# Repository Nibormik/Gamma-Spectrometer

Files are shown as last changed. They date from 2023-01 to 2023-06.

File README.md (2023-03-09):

# Gamma-Spectrometer
This is a Compact Gammaspectrometer Based On the Scematics and component choise of the [Open-Gamma-Detector](https://github.com/Open-Gamma-Project/Open-Gamma-Detector).
Its only Designed for testing purposes and should never be used in a production enviorment.  
<br>
This version of the Gamma spectrometer was designed with a few strict restrictions in mind.

#### Restrictions
<br>
The main rrestrictions:  <br>

- Power
    - <= 50ma
    - 5v
    - low noise
- physical limitations
    - pcb
        - width 50mm
        - height 30 mm
    - rocket interior diameter 98mm
        - max center height from pcb 38 mm
        - max edge height from pcb 28 mm 
- comunication
    - analog rocket input
        - update frequencey 2000hz - 4000hz
        - 8 bit resolution
    - digital input
        - 8bit digital paralell
        - estimated update frequency 20hz

## Similarities between projects

Since this is based upon the schematic of the Open Gamma Detector there are not allot of diffrences.  
Main diffrences are a diffrent cpu and the data output (wich is stricly analog)
Due to the enviorment, to-way comunictation is not possible so the bord does not support it.

The scintilator end general operational methon of the systen is equal to that of the Opgen Gamma Detector

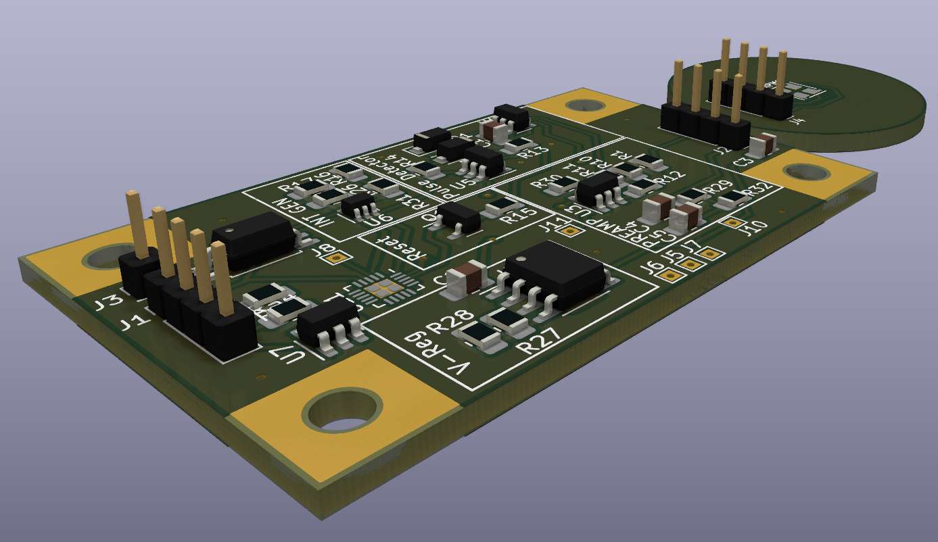
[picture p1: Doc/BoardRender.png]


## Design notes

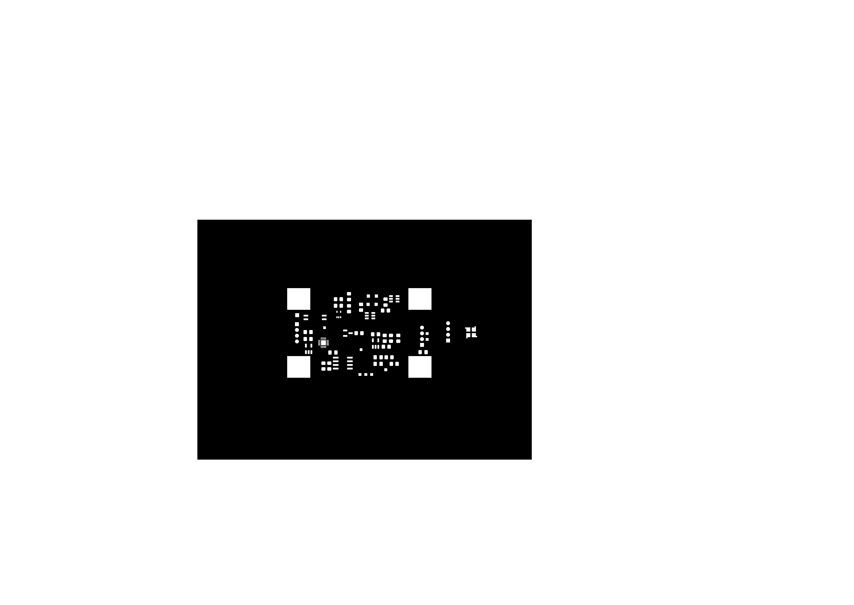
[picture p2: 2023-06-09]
Hardware/Pcb file/Gamma_spectrometer-F_Mask.png

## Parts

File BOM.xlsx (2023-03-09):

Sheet: Manglende Komponenter!
iD | AMOUT | LABEL | COMPONENT NAVN | KOMENTAR | FOOTPRINT | DATASHEET | KJØPS LINK
1 | 1 | Q1 | 2N7002 | Kan Erstates Med lignende Komponenter | Package_TO_SOT_SMD:SOT-23 | https://www.onsemi.com/pub/Collateral/NDS7002A-D.PDF | https://no.farnell.com/nexperia/2n7002-215/mosfet-n-ch-60v-0-3a-sot23/dp/1510761
2 | 1 | U2 | LM317L_SO8 | Regulator_Linear:LM317L_SO8 | Package_SO:SOIC-8_3.9x4.9mm_P1.27mm | http://www.ti.com/lit/ds/snvs775k/snvs775k.pdf | https://no.farnell.com/on-semiconductor/lm317lbdr2g/linear-volt-reg-adj-37v-0-1a-soic/dp/2534167?st=lm317l
3 | 2 | U3, U7 | OPA356AIDBVR | Amplifier_Operational:OPA356xxDBVR | Package_TO_SOT_SMD:SOT-23-5 | http://www.ti.com/lit/ds/symlink/opa356.pdf | https://www.digikey.no/en/products/detail/OPA356AIDBVT/296-12619-1-ND/446313
4 | 2 | U4, U5 | OPA357AIDBVR | Amplifier_Operational:OPA357xxDBVR | Package_TO_SOT_SMD:SOT-23-6 | http://www.ti.com/lit/ds/symlink/opa355.pdf | https://www.digikey.no/en/products/detail/texas-instruments/OPA357AIDBVR/1572552
5 | 1 | U6 | TLV3201AIDBVR |  | Package_TO_SOT_SMD:SOT-353_SC-70-5 |  | https://no.farnell.com/texas-instruments/tlv3201aidbvr/comparator-single-40ns-sot-23/dp/3005605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
6 | 1 | U8 | FODM217A | Kan Erstates Med lignende Komponenter | Package_SO:SOP-4_4.4x2.6mm_P1.27mm | https://www.onsemi.com/pub/Collateral/FODM214-D.PDF
7 | 1 | U11 | ATtiny1616-M | MCU_Microchip_ATtiny:ATtiny1616-M | Package_DFN_QFN:VQFN-20-1EP_3x3mm_P0.4mm_EP1.7x1.7mm | http://ww1.microchip.com/downloads/en/DeviceDoc/ATtiny3216_ATtiny1616-data-sheet-40001997B.pdf | https://no.farnell.com/microchip/attiny1616-mfr/mcu-8bit-avr-20mhz-vqfn-24/dp/2783011?st=attiny1616-m

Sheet: Gamma_spectrometer (4)
Column1 | Column2 | Column3 | Column4 | Column5 | Column6 | Column7 | Column8 | Column9 | Column10 | Column11
Source: | C:\Users\Nibne\Documents\Gamma Spectrometer\Hardware\Gamma_spectrometer.kicad_sch
Date: | 2/6/2023 2:52:58 PM
Tool: | Eeschema (6.0.8)
Generator: | C:\Program Files\KiCad\6.0\bin\scripting\plugins/bom_csv_grouped_by_value.py
Component Count: | 47
Individual Components:
Item | Qty | Reference(s) | Value | LibPart | Footprint | Datasheet | MANUFACTURER | MAXIMUM_PACKAGE_HEIGHT | PARTREV | STANDARD
 |  | C1 | C | Device:C | Capacitor_SMD:C_0805_2012Metric_Pad1.18x1.45mm_HandSolder | ~
 |  | C2 | C | Device:C | Capacitor_SMD:C_0805_2012Metric_Pad1.18x1.45mm_HandSolder | ~
 |  | C3 | C | Device:C | Capacitor_SMD:C_0805_2012Metric_Pad1.18x1.45mm_HandSolder | ~
 |  | C4 | 10n | Device:C | Capacitor_SMD:C_0805_2012Metric_Pad1.18x1.45mm_HandSolder | ~
 |  | C5 | 10n | Device:C | Capacitor_SMD:C_0805_2012Metric_Pad1.18x1.45mm_HandSolder | ~
 |  | D1 | PMEG6010CEH | Diode:PMEG6010CEH | Diode_SMD:D_SOD-123F | https://assets.nexperia.com/documents/data-sheet/PMEG6010CEH_PMEG6010CEJ.pdf
 |  | D2 | PMEG6010CEH | Diode:PMEG6010CEH | Diode_SMD:D_SOD-123F | https://assets.nexperia.com/documents/data-sheet/PMEG6010CEH_PMEG6010CEJ.pdf
 |  | J1 | Conn_01x04 | Connector_Generic:Conn_01x04 | Connector_PinHeader_2.00mm:PinHeader_1x04_P2.00mm_Vertical | ~
 |  | J2 | Conn_01x04 | Connector_Generic:Conn_01x04 | Connector_PinHeader_2.00mm:PinHeader_1x04_P2.00mm_Vertical | ~
 |  | J3 | Conn_01x01 | Connector_Generic:Conn_01x01 | Connector_PinHeader_2.00mm:PinHeader_1x01_P2.00mm_Vertical | ~
 |  | J4 | Conn_01x04 | Connector_Generic:Conn_01x04 | Connector_PinHeader_2.00mm:PinHeader_1x04_P2.00mm_Vertical | ~
 |  | J5 | Test Pad | Connector:Conn_01x01_Female | TestPoint:TestPoint_THTPad_1.0x1.0mm_Drill0.5mm | ~
 |  | J6 | Test Pad | Connector:Conn_01x01_Female | TestPoint:TestPoint_THTPad_1.0x1.0mm_Drill0.5mm | ~
 |  | J7 | Test Pad | Connector:Conn_01x01_Female | TestPoint:TestPoint_THTPad_1.0x1.0mm_Drill0.5mm | ~
 |  | J8 | Test Pad | Connector:Conn_01x01_Female | TestPoint:TestPoint_THTPad_1.0x1.0mm_Drill0.5mm | ~
 |  | J9 | Test Pad | Connector:Conn_01x01_Female | TestPoint:TestPoint_THTPad_1.0x1.0mm_Drill0.5mm | ~
 |  | J10 | Test Pad | Connector:Conn_01x01_Female | TestPoint:TestPoint_THTPad_1.0x1.0mm_Drill0.5mm | ~
 |  | J11 | Test Pad | Connector:Conn_01x01_Female | TestPoint:TestPoint_THTPad_1.0x1.0mm_Drill0.5mm | ~
 |  | J12 | Test Pad | Connector:Conn_01x01_Female | TestPoint:TestPoint_THTPad_1.0x1.0mm_Drill0.5mm | ~
 |  | Q1 | 2N7002 | Transistor_FET:2N7002 | Package_TO_SOT_SMD:SOT-23 | https://www.onsemi.com/pub/Collateral/NDS7002A-D.PDF
 |  | R1 | 49.9 | Device:R | Resistor_SMD:R_0805_2012Metric_Pad1.20x1.40mm_HandSolder | ~
 |  | R10 | 10 | Device:R | Resistor_SMD:R_0805_2012Metric_Pad1.20x1.40mm_HandSolder | ~
 |  | R11 | 10 | Device:R | Resistor_SMD:R_0805_2012Metric_Pad1.20x1.40mm_HandSolder | ~
 |  | R12 | 49.9 | Device:R | Resistor_SMD:R_0805_2012Metric_Pad1.20x1.40mm_HandSolder | ~
 |  | R13 | 49.9 | Device:R | Resistor_SMD:R_0805_2012Metric_Pad1.20x1.40mm_HandSolder | ~
 |  | R14 | 1000 | Device:R | Resistor_SMD:R_0805_2012Metric_Pad1.20x1.40mm_HandSolder | ~
 |  | R15 | 1000 | Device:R | Resistor_SMD:R_0805_2012Metric_Pad1.20x1.40mm_HandSolder | ~
 |  | R16 | 1000 | Device:R | Resistor_SMD:R_0805_2012Metric_Pad1.20x1.40mm_HandSolder | ~
 |  | R17 | 107K | Device:R | Resistor_SMD:R_0805_2012Metric_Pad1.20x1.40mm_HandSolder | ~
 |  | R26 | 107K | Device:R | Resistor_SMD:R_0805_2012Metric_Pad1.20x1.40mm_HandSolder | ~
 |  | R27 | ? | Device:R | Resistor_SMD:R_0805_2012Metric_Pad1.20x1.40mm_HandSolder | ~
 |  | R28 | ? | Device:R | Resistor_SMD:R_0805_2012Metric_Pad1.20x1.40mm_HandSolder | ~
 |  | R29 | 49.9 | Device:R | Resistor_SMD:R_0805_2012Metric_Pad1.20x1.40mm_HandSolder | ~
 |  | R30 | ? | Device:R | Resistor_SMD:R_0805_2012Metric_Pad1.20x1.40mm_HandSolder | ~
 |  | R31 | ? | Device:R | Resistor_SMD:R_0805_2012Metric_Pad1.20x1.40mm_HandSolder | ~
 |  | R32 | 49.9 | Device:R | Resistor_SMD:R_0805_2012Metric_Pad1.20x1.40mm_HandSolder | ~
 |  | R33 | 1000 | Device:R | Resistor_SMD:R_0805_2012Metric_Pad1.20x1.40mm_HandSolder | ~
 |  | R34 | 1000 | Device:R | Resistor_SMD:R_0805_2012Metric_Pad1.20x1.40mm_HandSolder | ~
 |  | SIPM1 | MICROFC-30035-SMT-TR1 | MICROFC-30035-SMT-TR1:MICROFC-30035-SMT-TR1 | MICROFC-30035-SMT-TR1:XDCR_MICROFC-30035-SMT-TR1 |  | On Semiconductor | 0.70 mm | Issue O | Manufacturer Recommendations
 |  | U2 | LM317L_SO8 | Regulator_Linear:LM317L_SO8 | Package_SO:SOIC-8_3.9x4.9mm_P1.27mm | http://www.ti.com/lit/ds/snvs775k/snvs775k.pdf
 |  | U3 | OPA356xxDBV | Amplifier_Operational:OPA356xxDBV | Package_TO_SOT_SMD:SOT-23-5 | http://www.ti.com/lit/ds/symlink/opa356.pdf
 |  | U4 | OPA357AIDVBR | Amplifier_Operational:OPA355NA | Package_TO_SOT_SMD:SOT-23-6 | http://www.ti.com/lit/ds/symlink/opa355.pdf
 |  | U5 | OPA357AIDVBR | Amplifier_Operational:OPA355NA | Package_TO_SOT_SMD:SOT-23-6 | http://www.ti.com/lit/ds/symlink/opa355.pdf
 |  | U6 | LMV7219M7 | Comparator:LMV7219M7 | Package_TO_SOT_SMD:SOT-353_SC-70-5 | https://www.ti.com/lit/ds/symlink/lmv7219.pdf
 |  | U7 | OPA356xxDBV | Amplifier_Operational:OPA356xxDBV | Package_TO_SOT_SMD:SOT-23-5 | http://www.ti.com/lit/ds/symlink/opa356.pdf
 |  | U8 | FODM217A | Isolator:FODM217A | Package_SO:SOP-4_4.4x2.6mm_P1.27mm | https://www.onsemi.com/pub/Collateral/FODM214-D.PDF
 |  | U11 | ATtiny1616-M | MCU_Microchip_ATtiny:ATtiny1616-M | Package_DFN_QFN:VQFN-20-1EP_3x3mm_P0.4mm_EP1.7x1.7mm | http://ww1.microchip.com/downloads/en/DeviceDoc/ATtiny3216_ATtiny1616-data-sheet-40001997B.pdf
Collated Components:
Item | Qty | Reference(s) | Value | LibPart | Footprint | Datasheet | MANUFACTURER | MAXIMUM_PACKAGE_HEIGHT | PARTREV | STANDARD
1 | 3 | C1, C2, C3 | C |  | Capacitor_SMD:C_0805_2012Metric_Pad1.18x1.45mm_HandSolder | ~
2 | 2 | C4, C5 | 10n |  | Capacitor_SMD:C_0805_2012Metric_Pad1.18x1.45mm_HandSolder | ~
3 | 2 | D1, D2 | PMEG6010CEH | Kan Erstates Med lignende Komponenter | Diode_SMD:D_SOD-123F | https://assets.nexperia.com/documents/data-sheet/PMEG6010CEH_PMEG6010CEJ.pdf
4 | 3 | J1, J2, J4 | Conn_01x04 | 1stk Rakett konnector 2stk pin header | Connector_PinHeader_2.00mm:PinHeader_1x04_P2.00mm_Vertical | ~
5 | 1 | J3 | Conn_01x01 | rakett CLK konnector | Connector_PinHeader_2.00mm:PinHeader_1x01_P2.00mm_Vertical | ~
6 | 8 | J5, J6, J7, J8, J9, J10, J11, J12 | Test Pad |  | TestPoint:TestPoint_THTPad_1.0x1.0mm_Drill0.5mm | ~
7 | 1 | Q1 | 2N7002 | Kan Erstates Med lignende Komponenter | Package_TO_SOT_SMD:SOT-23 | https://www.onsemi.com/pub/Collateral/NDS7002A-D.PDF
8 | 5 | R1, R12, R13, R29, R32 | 49.9 |  | Resistor_SMD:R_0805_2012Metric_Pad1.20x1.40mm_HandSolder | ~
9 | 2 | R10, R11 | 10 |  | Resistor_SMD:R_0805_2012Metric_Pad1.20x1.40mm_HandSolder | ~
10 | 5 | R14, R15, R16, R33, R34 | 1000 |  | Resistor_SMD:R_0805_2012Metric_Pad1.20x1.40mm_HandSolder | ~
11 | 2 | R17, R26 | 107K |  | Resistor_SMD:R_0805_2012Metric_Pad1.20x1.40mm_HandSolder | ~
12 | 4 | R27, R28, R30, R31 | ? | må testes for og finne verdi | Resistor_SMD:R_0805_2012Metric_Pad1.20x1.40mm_HandSolder | ~
13 | 1 | SIPM1 | MICROFC-30035-SMT-TR1 |  | MICROFC-30035-SMT-TR1:XDCR_MICROFC-30035-SMT-TR1 |  | On Semiconductor | 0.70 mm | Issue O | Manufacturer Recommendations
14 | 1 | U2 | LM317L_SO8 | Regulator_Linear:LM317L_SO8 | Package_SO:SOIC-8_3.9x4.9mm_P1.27mm | http://www.ti.com/lit/ds/snvs775k/snvs775k.pdf
15 | 2 | U3, U7 | OPA356AIDBVR | Amplifier_Operational:OPA356xxDBVR | Package_TO_SOT_SMD:SOT-23-5 | http://www.ti.com/lit/ds/symlink/opa356.pdf
16 | 2 | U4, U5 | OPA357AIDBVR | Amplifier_Operational:OPA357xxDBVR | Package_TO_SOT_SMD:SOT-23-6 | http://www.ti.com/lit/ds/symlink/opa355.pdf
17 | 1 | U6 | LMV7219M7 | Comparator:LMV7219M7 | Package_TO_SOT_SMD:SOT-353_SC-70-5 | https://www.ti.com/lit/ds/symlink/lmv7219.pdf
18 | 1 | U8 | FODM217A | Kan Erstates Med lignende Komponenter | Package_SO:SOP-4_4.4x2.6mm_P1.27mm | https://www.onsemi.com/pub/Collateral/FODM214-D.PDF
19 | 1 | U11 | ATtiny1616-M | MCU_Microchip_ATtiny:ATtiny1616-M | Package_DFN_QFN:VQFN-20-1EP_3x3mm_P0.4mm_EP1.7x1.7mm | http://ww1.microchip.com/downloads/en/DeviceDoc/ATtiny3216_ATtiny1616-data-sheet-40001997B.pdf

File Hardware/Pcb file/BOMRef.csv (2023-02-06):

ID | Name | Designator | Footprint | Quantity | Manufacturer Part | Manufacturer | Supplier | Supplier Part | Price
1 | XL-2012UOC | ACT | LED0805-RD_ORANGE | 1 | XL-2012UOC | XINGLIGHT(成兴光) | LCSC | C965813 | 0.008
2 | 4.7uF | C1,C5,C9,C10,C11 | C0805 | 5 | CL21A475KBQNNNE | SAMSUNG | LCSC | C98192 | 0.028
3 | 100nF | C2,C3,C4,C6,C7 | C0805 | 5 | CL21B104KBCNNNC | SAMSUNG | LCSC | C1711 | 0.003
4 | 220pF | C8 | C0805 | 1 | ECHU1H221JX5 | PANASONIC | LCSC | C178426 | 0.279
5 | PMEG6010CEH | D1,D2,D3 | SOD-123FL_L2.7-W1.8-LS3.8-RD | 3 | PMEG6010CEH,115 | NXP | LCSC | C110797 | 0.278
6 | 47uH | L1 | IND-SMD_L5.0-W5.0 | 1 | GCNR5040-470MC | GLE | LCSC | C439375 | 0.057
7 | 2N7002,215 | Q1 | SOT-23_L2.9-W1.3-P1.90-LS2.4-BR | 1 | 2N7002,215 | Nexperia | LCSC | C65189 | 0.042
8 | 107kΩ | R1,R11,R22 | R0805 | 3 | 0805W8F1073T5E | UniOhm | LCSC | C17412 | 0.003
9 | 10kΩ | R2,R9,R10 | RES-ADJ-TH_3P-L10.0-W10.0-P2.50-L | 3 | 3296W-1-103 | Chengdu Guosheng Tech | LCSC | C118954 | 0.151
10 | 1K | R3,R6,R7,R8 | R0805 | 4 | 0805W8F1001T5E | UniOhm | LCSC | C17513 | 0.002
11 | 10Ω | R5,R12,R14 | R0805_NEW | 3 | 0805W8F100JT5E | UniOhm | LCSC | C17415 | 0.002
12 | 10kΩ | R13,R15 | R0805 | 2 | 0805W8F1002T5E | UniOhm | LCSC | C17414 | 0.001
13 | 49.9Ω | R16,R17,R20,R21 | R0805 | 4 | 0805W8F499JT5E | UniOhm | LCSC | C17720 | 0.002
14 | 2kΩ | R19 | RES-ADJ-TH_3296W-L | 1 | 3296W-1-202LF | Bochen | LCSC | C118206 | 0.195
15 | TLV3201AIDBVR | U1 | SOT-23-5_L3.0-W1.7-P0.95-LS2.8-BR | 1 | TLV3201AIDBVR | TI | LCSC | C105188 | 0.554
16 | LM4040AIM3-3.0+T | U2 | SOT-23-3_L2.9-W1.6-P1.90-LS2.8-BR | 1 | LM4040AIM3-3.0+T | MAXIM | LCSC | C143326 | 1.067
17 | PI-PICO-SMD | U3 | RASPBERRY PICO SMD | 1 | Raspberry Pi Pico | Raspberry Pi Ltd |  | Raspberry Pi Pico
18 | MAX5026EUT+T | U5 | SOT-23-6_L2.9-W1.6-P0.95-LS2.8-BL | 1 | MAX5026EUT+T | Maxim Integrated | Mouser | 700-MAX5026EUTT
19 | OPA356AIDBVR | U6 | SOT-23-5_L3.0-W1.7-P0.95-LS2.8-BR | 1 | OPA356AIDBVR | Texas Instruments | LCSC | C183100 | 3.175
20 | OPA357AIDBVR | U7,U8 | SOT-23-6_L2.9-W1.6-P0.95-LS2.8-BR | 2 | OPA357AIDBVR | TI | LCSC | C139385 | 3.515

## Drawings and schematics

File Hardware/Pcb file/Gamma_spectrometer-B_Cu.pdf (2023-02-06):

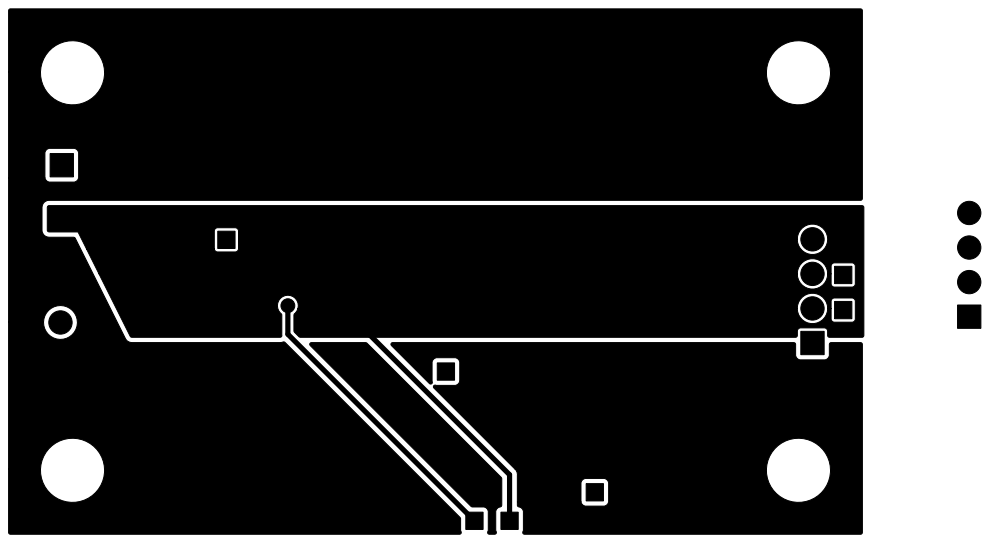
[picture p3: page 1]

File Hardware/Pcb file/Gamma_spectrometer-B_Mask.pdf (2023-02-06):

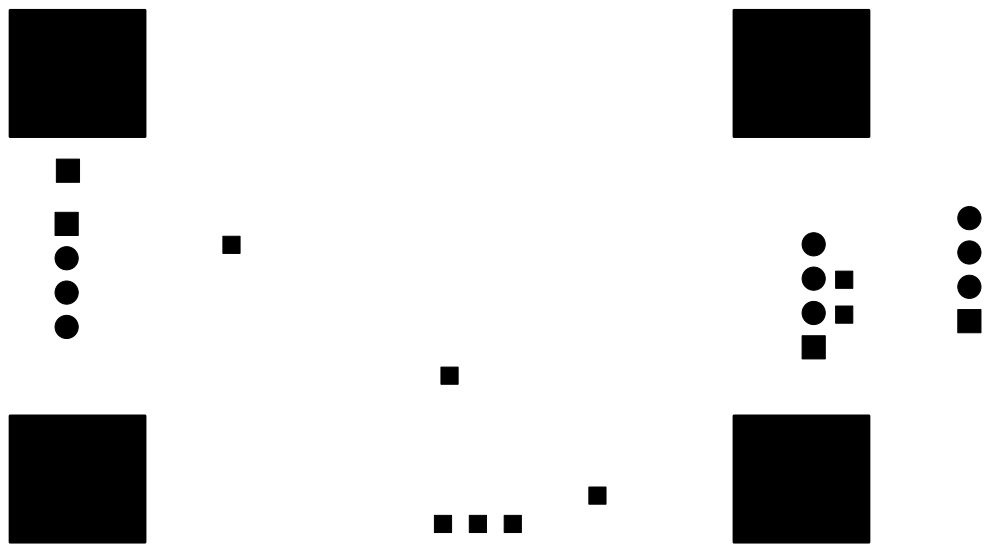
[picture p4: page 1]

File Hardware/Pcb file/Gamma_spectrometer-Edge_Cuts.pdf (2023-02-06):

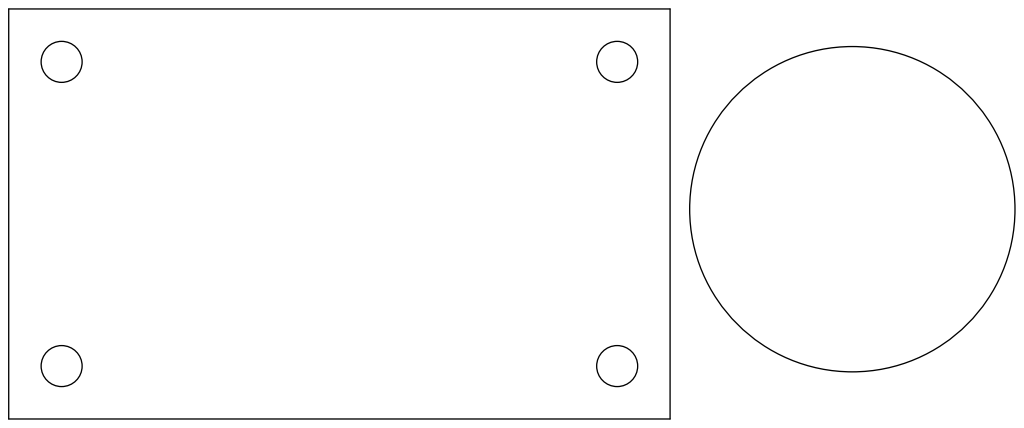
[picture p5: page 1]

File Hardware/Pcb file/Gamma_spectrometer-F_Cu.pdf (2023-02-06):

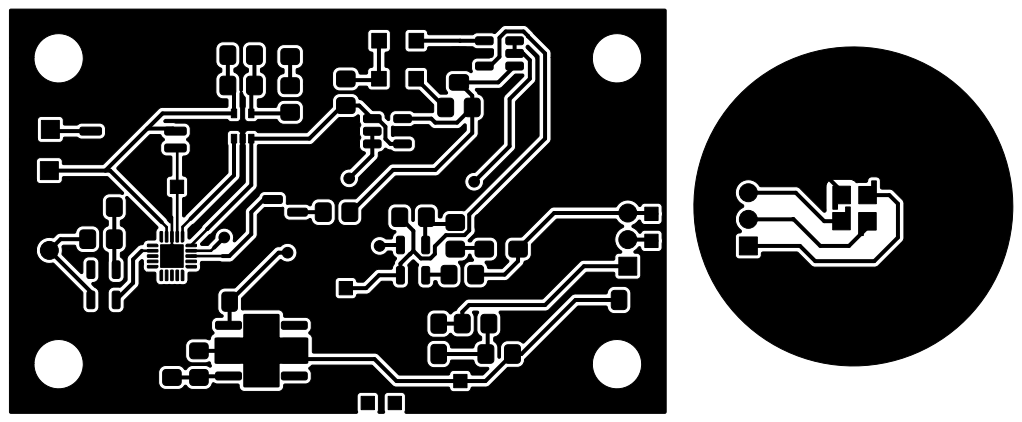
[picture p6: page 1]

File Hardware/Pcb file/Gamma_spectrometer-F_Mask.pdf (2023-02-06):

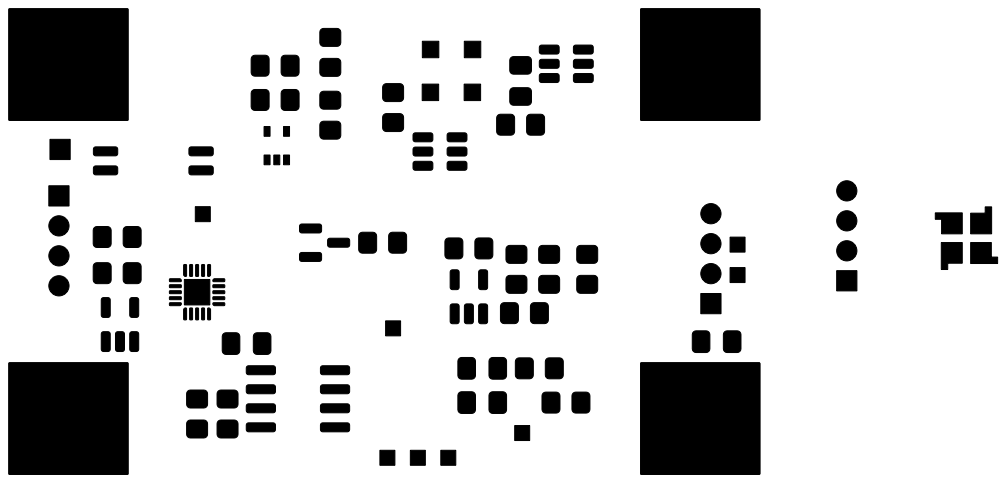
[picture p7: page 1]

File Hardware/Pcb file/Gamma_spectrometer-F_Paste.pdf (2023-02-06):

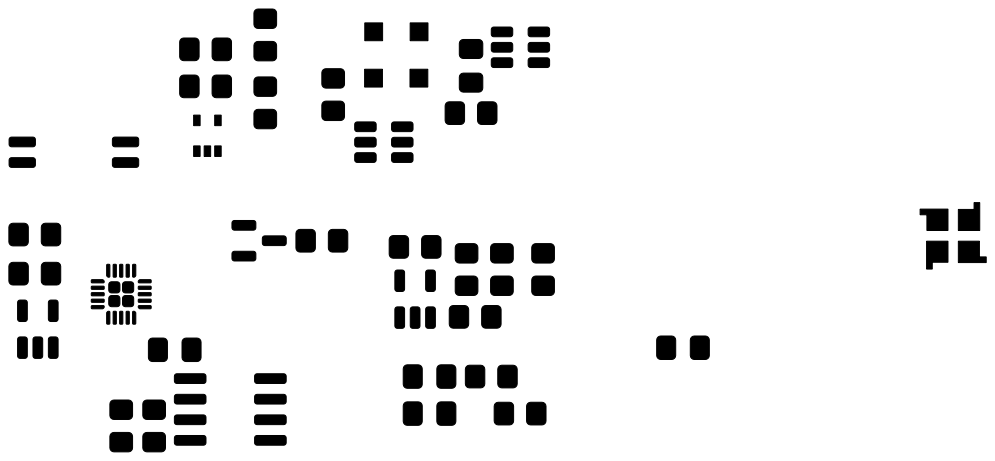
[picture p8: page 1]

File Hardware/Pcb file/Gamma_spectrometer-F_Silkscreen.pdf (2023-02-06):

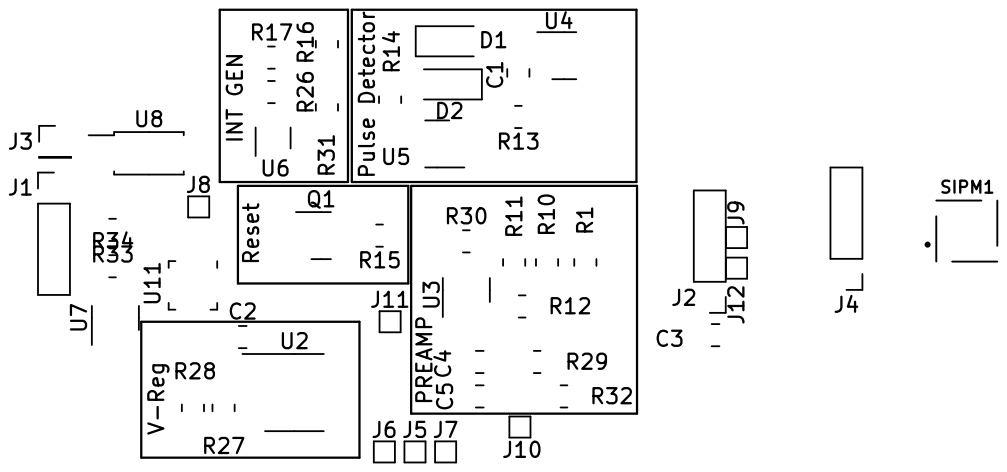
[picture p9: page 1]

INT GEN V-Reg PREAMP Reset R31 Pulse Detector J2 R12 R17 C4 R13

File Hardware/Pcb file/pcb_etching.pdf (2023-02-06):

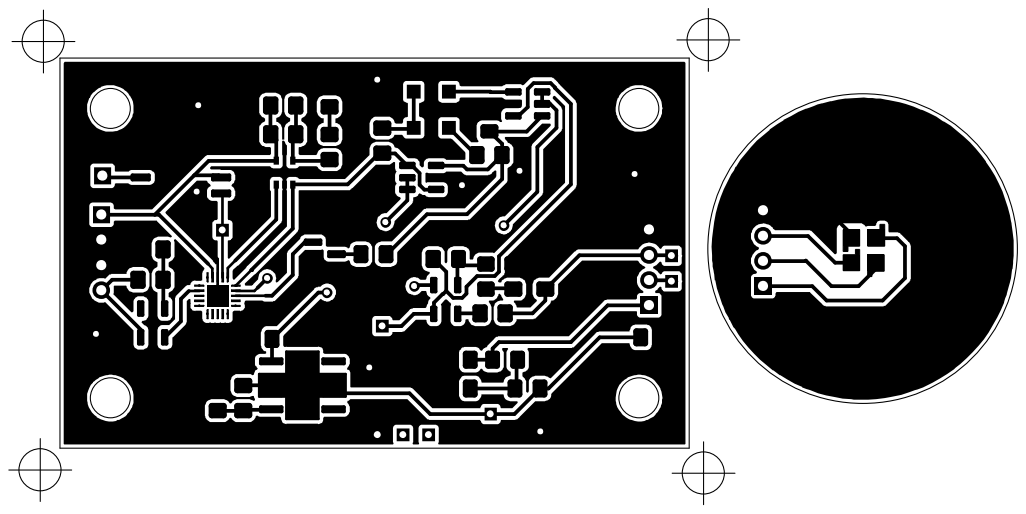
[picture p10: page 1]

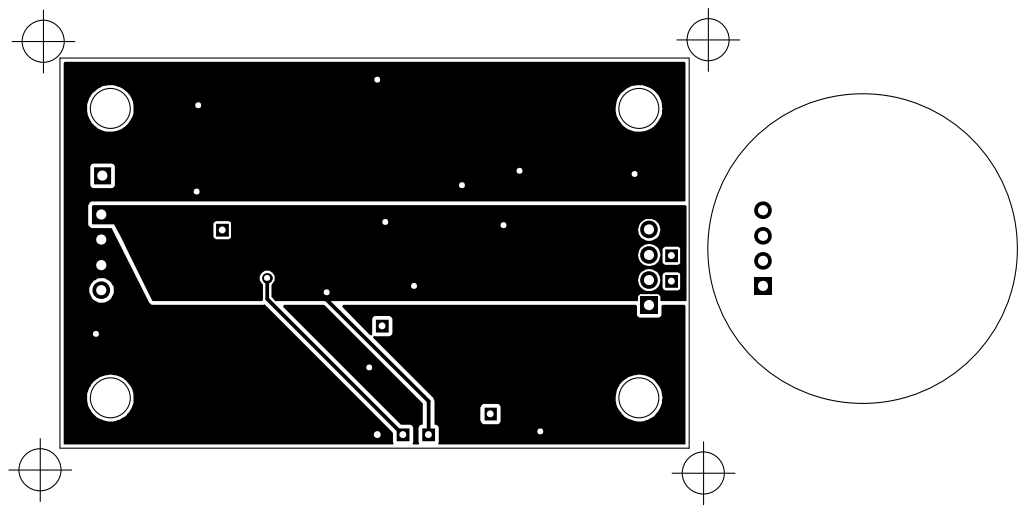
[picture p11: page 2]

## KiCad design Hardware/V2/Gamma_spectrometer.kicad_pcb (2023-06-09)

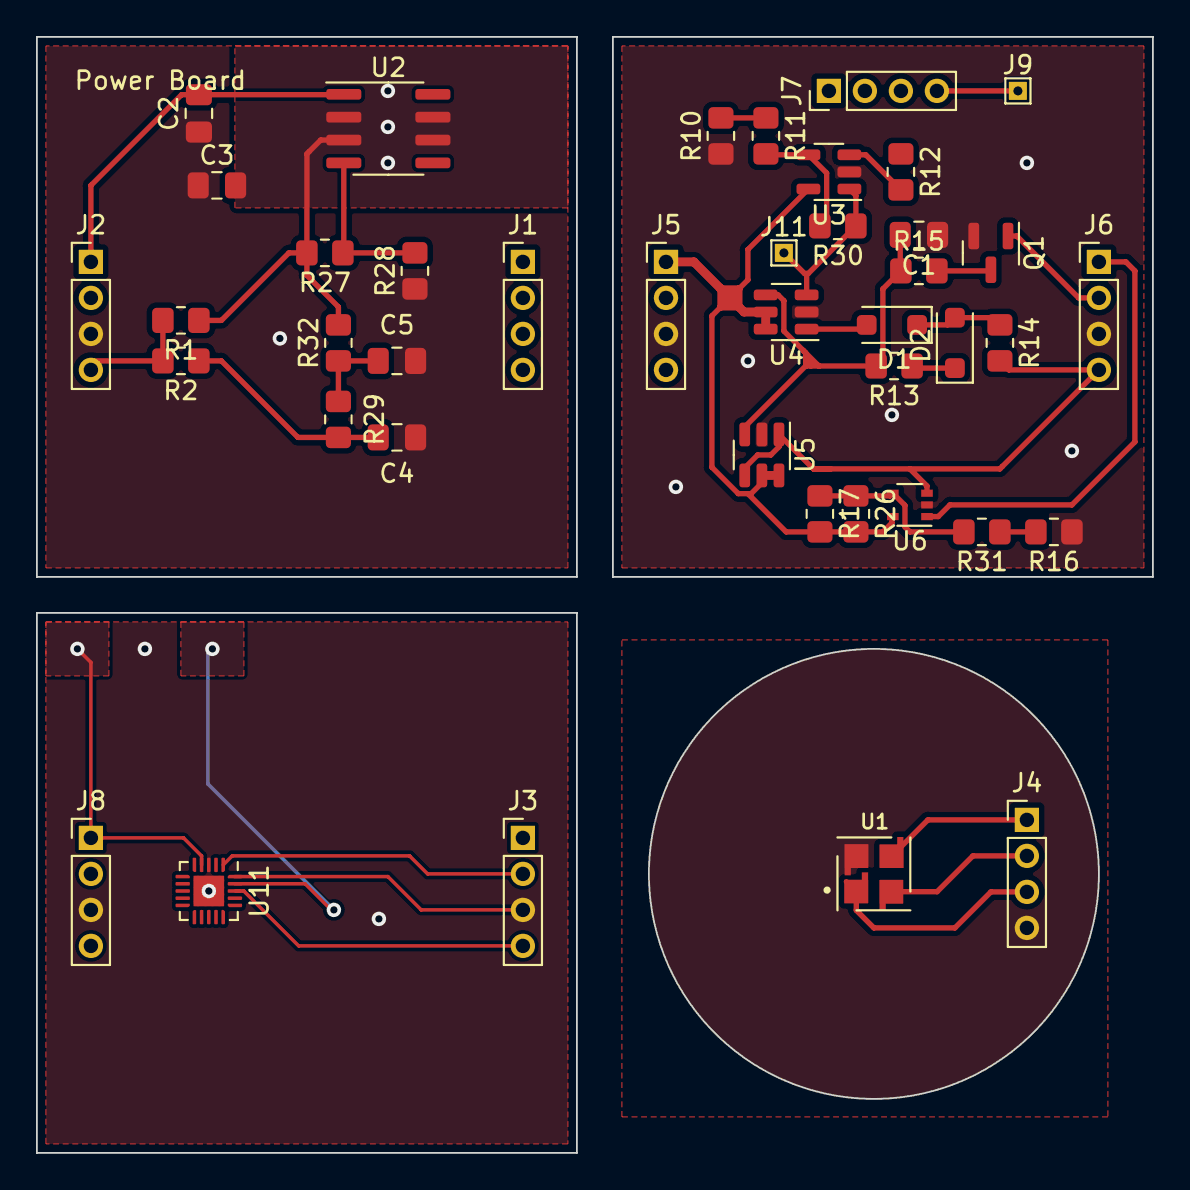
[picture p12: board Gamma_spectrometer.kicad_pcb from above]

Board: 2 copper layers, 62.0 x 62.0 mm, 42 parts (0 on the bottom side), 32 nets.

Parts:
C1, C2, C3: C; C_0805_2012Metric_Pad1.18x1.45mm_HandSolder
C4, C5: 10n; C_0805_2012Metric_Pad1.18x1.45mm_HandSolder
D1, D2: PMEG6010CEH; D_SOD-123F
J1, J2, J3, J4, J5, J6, J7, J8: Conn_01x04; PinHeader_1x04_P2.00mm_Vertical
J9, J11: Test Pad; TestPoint_THTPad_1.0x1.0mm_Drill0.5mm
Q1: 2N7002; SOT-23
R1, R2: 0; R_0805_2012Metric_Pad1.20x1.40mm_HandSolder
R10, R11: 10; R_0805_2012Metric_Pad1.20x1.40mm_HandSolder
R12, R13, R29, R32: 49.9; R_0805_2012Metric_Pad1.20x1.40mm_HandSolder
R14, R15, R16: 1000; R_0805_2012Metric_Pad1.20x1.40mm_HandSolder
R17, R26: 107K; R_0805_2012Metric_Pad1.20x1.40mm_HandSolder
R27, R28, R30, R31: ?; R_0805_2012Metric_Pad1.20x1.40mm_HandSolder
U1: MICROFC-30035-SMT-TR1; XDCR_MICROFC-30035-SMT-TR1
U2: LM317L_SO8; SOIC-8_3.9x4.9mm_P1.27mm
U3: OPA356xxDBV; SOT-23-5
U4, U5: OPA357AIDVBR; SOT-23-6
U6: LMV7219M7; SOT-353_SC-70-5
U11: ATtiny1616-M; VQFN-20-1EP_3x3mm_P0.4mm_EP1.7x1.7mm

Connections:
+5V: J5.1, J8.1, R17.2, R26.2, U3.5 (V+), U4.5 (ENABLE), U4.6 (V+), U5.5 (ENABLE), U5.6 (V+), U6.5 (V+), U11.4 (VCC)
GND: C1.1, J5.3, J6.3, Q1.2 (S), R10.1, R16.1, U3.2 (V-), U4.2 (V-), U5.2 (V-), U6.2 (V-)
GND1: J4.4, U1.4
GND2: C2.1, C3.1, C4.2, C5.2, J2.3, R28.1
GND3: J3.3, J8.3, U11.3 (GND), U11.21 (GND)
INT: J6.1, U6.1
unnamed: C3.2, R1.1, R27.2, R32.2, U2.2 (VO), U2.3 (VO), U2.6 (VO), U2.7 (VO)
unnamed: C4.1, R2.1, R29.1
unnamed: C5.1, R29.2, R32.1
unnamed: D1.2 (A), U4.1
unnamed: D1.1 (K), D2.2 (A), R14.1
unnamed: D2.1 (K), R13.1
unnamed: C2.2, J2.1, U2.1 (VI)
unnamed: J2.4, R1.2, R2.2
unnamed: J3.1, U11.1 (PA2)
unnamed: J3.2, U11.20 (PA1)
unnamed: J3.4, U11.18 (PC3)
unnamed: J4.1, U1.3
unnamed: J4.2, U1.2
unnamed: J4.3, U1.1
unnamed: J11.1, R30.1, U3.1, U4.3 (+)
unnamed: Q1.3 (D), R15.2
unnamed: R10.2, R11.1
unnamed: R16.2, R31.1
unnamed: R27.1, R28.2, U2.4 (ADJ)
unnamed: R12.2, U3.3 (+)
unnamed: R11.2, R30.2, U3.4 (-)
unnamed: C1.2, R13.2, R15.1, U4.4 (-), U5.3 (+)
unnamed: R17.1, R26.1, R31.2, U6.4 (-)
Reset: J6.2, Q1.1 (G)
SIPM: J7.1, J7.2, J7.3, J7.4, J9.1, R12.1
Signal: J6.4, R14.2, U5.1, U5.4 (-), U6.3 (+)

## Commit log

2023-01-13 BOM scv update
    [Gamma_spectrometer.csv, Gamma_spectrometer.kicad_sch]
2023-01-13 some stuff
    [BOM.xlsx, Gamma_spectrometer.csv, Gamma_spectrometer.kicad_pcb]
2023-01-13 code stuff i guess
    [Gamma_spectrometer.kicad_sch]
2023-03-09 fixed som BOM stuff
    [BOM.xlsx, Gamma_spectrometer.kicad_pcb, Gamma_spectrometer.kicad_sch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]
2023-06-09 Reworked entre board to be modular now more practical to use outside of the very limited desig limitations originally planed
    [Gamma_spectrometer.csv, Gamma_spectrometer.kicad_pcb, Gamma_spectrometer.kicad_sch]
